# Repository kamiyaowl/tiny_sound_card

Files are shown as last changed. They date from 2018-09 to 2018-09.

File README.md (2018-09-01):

# tiny_sound_card
名刺サイズのボードでArduino Pro Mini同等のボードで、mp3を再生したりできるモジュール

ドア開閉時の音声再生モジュールや簡易mp3プレイヤーを簡単に制作できます。

3d image

## 特徴

* Arduino Pro Miniと同じ開発環境で開発を行え、mp3の音声再生が簡単に行なえます
* スイッチ、mp3再生モジュール、外部スイッチ、SPI、I2Cの準備がしており拡張が容易です
* 表面実装部品が2個のみと、はんだづけの難易度が低いです
* 殆どの部品を秋月電子で購入可能です

## HW仕様

ピン番号 | ボード機能 | ピン機能 | 備考
--------|-------|------|---
D0 | PinHeader | UART RXD | Arduino Bootloader書き込み用
D1 | PinHeader | UART TXD | Arduino Bootloader書き込み用
D2 | LED | Digital Output |
D3 | PinHeader | Digital Input | スイッチ入力用。チャタリング防止回路有
D4 | SW0 | Digital Input | スライドスイッチ
D5 | BTN0 | Digital Input | タクトスイッチ0
D6 | BTN1 | Digital Input | タクトスイッチ1
D7 | BTN2 | Digital Input | タクトスイッチ2
D8 | BTN3 | Digital Input | タクトスイッチ3
D9 | mp3player Control | UART TXD | mp3モジュール制御用
D10 | PinHeader | Digital Output | 外部モジュール接続用SPI
D11 | PinHeader | SPI MOSI | 外部モジュール接続用SPI
D12 | PinHeader | SPI MISO | 外部モジュール接続用SPI
D13 | PinHeader | SPI SCK | 外部モジュール接続用SPI
A0(D14) | mp3player Control | UART RXD | mp3モジュール制御用
A1(D15) | mp3player Control | Digital Input | mp3player再生中にLow
A2(D16) | mp3player Power Control | Digital Output | mp3player電源EN
A3(D17) | mp3player Power Control | Digital Input | mp3player電源/FAULT
A4 | PinHeader | I2C SDA | 外部モジュール接続用I2C
A5 | PinHeader | I2C SCL | 外部モジュール接続用I2C

* スイッチ回路(D3,4,5,6,7,8)にはチャタリング防止回路を実装
* SPI端子はISP(In System Programming)回路も兼用しています
* mp3 playerとはSoftwareSerialを使用して通信を行います
  * [Datasheet](http://akizukidenshi.com/download/ds/dfrobot/DFPlayer_Mini_Manual.pdf)
* mp3 playerモジュールの消費電力が大きいため、ハイサイドスイッチで電源断できるようになっています
  * 不要であれば、U1の1-5pinを短絡してください
   * [Datasheet](https://docs-apac.rs-online.com/webdocs/140d/0900766b8140da8f.pdf)

## SW仕様

準備予定

## 製造ファイル

| ファイルパス | 種別 |
| --- | --- |
`kicad/gerber` | 基盤製造ファイル
`kicad/acrylic_cover/tiny_sound_card-Eco1.User.svg` | 表面アクリルカバー
`kicad/acrylic_cover/tiny_sound_card-Eco2.User.svg` | 裏面アクリルカバー

## 購入部品

| 参照記号 | 購入先 | 数量 | URL |
|---|---|----|---|
| U1 | RS Components | 1  | https://jp.rs-online.com/web/p/intelligent-power-switches/8805406/ |
| R7,R9,R10,R11,R12,R13 | 秋月 | 1  | http://akizukidenshi.com/catalog/g/gR-25473/ |
| R2,R3,R6 | 秋月 | 1  | http://akizukidenshi.com/catalog/g/gR-25103/ |
| R1,R4 | 秋月 | 1  | http://akizukidenshi.com/catalog/g/gR-25102/ |
| CP1 | 秋月 | 1  | http://akizukidenshi.com/catalog/g/gP-10596/ |
| SW1,SW5 | 秋月 | 1  | http://akizukidenshi.com/catalog/g/gP-08789/ |
| Y1 | 秋月 | 1  | http://akizukidenshi.com/catalog/g/gP-08671/ |
| C4,C5 | 秋月 | 1  | http://akizukidenshi.com/catalog/g/gP-04060/ |
| SW2,SW3,SW4,SW6 | 秋月 | 4  | http://akizukidenshi.com/catalog/g/gP-03647/ |
| F1 | 秋月 | 1  | http://akizukidenshi.com/catalog/g/gP-00777/ |
| C1,C2,C3,C6,C7,C9,C10,C11,C12,C13 | 秋月 | 1  | http://akizukidenshi.com/catalog/g/gP-00090/ |
| M1 | 秋月 | 1  | http://akizukidenshi.com/catalog/g/gM-12544/ |
| D1 | 秋月 | 1  | http://akizukidenshi.com/catalog/g/gI-11578/ |
| IC1 | 秋月 | 1  | http://akizukidenshi.com/catalog/g/gI-04386/ |
| J1 | 秋月 | 1  | http://akizukidenshi.com/catalog/g/gC-02460/ |
| P2 | 秋月 | 1  | http://akizukidenshi.com/catalog/g/gC-01627/ |
| CON1 | 秋月 | 1  | http://akizukidenshi.com/catalog/g/gC-00077/ |

## License

MIT

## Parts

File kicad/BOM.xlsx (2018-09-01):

ID | 参照記号 | 購入先 | 数量 | URL
15 | U1 | RS Components | 1 | https://jp.rs-online.com/web/p/intelligent-power-switches/8805406/
13 | R7,R9,R10,R11,R12,R13 | 秋月 | 1 | http://akizukidenshi.com/catalog/g/gR-25473/
12 | R2,R3,R6 | 秋月 | 1 | http://akizukidenshi.com/catalog/g/gR-25103/
23 | R1,R4 | 秋月 | 1 | http://akizukidenshi.com/catalog/g/gR-25102/
21 | CP1 | 秋月 | 1 | http://akizukidenshi.com/catalog/g/gP-10596/
14 | SW1,SW5 | 秋月 | 1 | http://akizukidenshi.com/catalog/g/gP-08789/
16 | Y1 | 秋月 | 1 | http://akizukidenshi.com/catalog/g/gP-08671/
3 | C4,C5 | 秋月 | 1 | http://akizukidenshi.com/catalog/g/gP-04060/
22 | SW2,SW3,SW4,SW6 | 秋月 | 4 | http://akizukidenshi.com/catalog/g/gP-03647/
6 | F1 | 秋月 | 1 | http://akizukidenshi.com/catalog/g/gP-00777/
2 | C1,C2,C3,C6,C7,C9,C10,C11,C12,C13 | 秋月 | 1 | http://akizukidenshi.com/catalog/g/gP-00090/
17 | M1 | 秋月 | 1 | http://akizukidenshi.com/catalog/g/gM-12544/
5 | D1 | 秋月 | 1 | http://akizukidenshi.com/catalog/g/gI-11578/
7 | IC1 | 秋月 | 1 | http://akizukidenshi.com/catalog/g/gI-04386/
8 | J1 | 秋月 | 1 | http://akizukidenshi.com/catalog/g/gC-02460/
10 | P2 | 秋月 | 1 | http://akizukidenshi.com/catalog/g/gC-01627/
4 | CON1 | 秋月 | 1 | http://akizukidenshi.com/catalog/g/gC-00077/
24 | G***
1 | P10,P9,P8,P4
11 | P5
9 | P1
18 | P4
19 | P6
20 | P7

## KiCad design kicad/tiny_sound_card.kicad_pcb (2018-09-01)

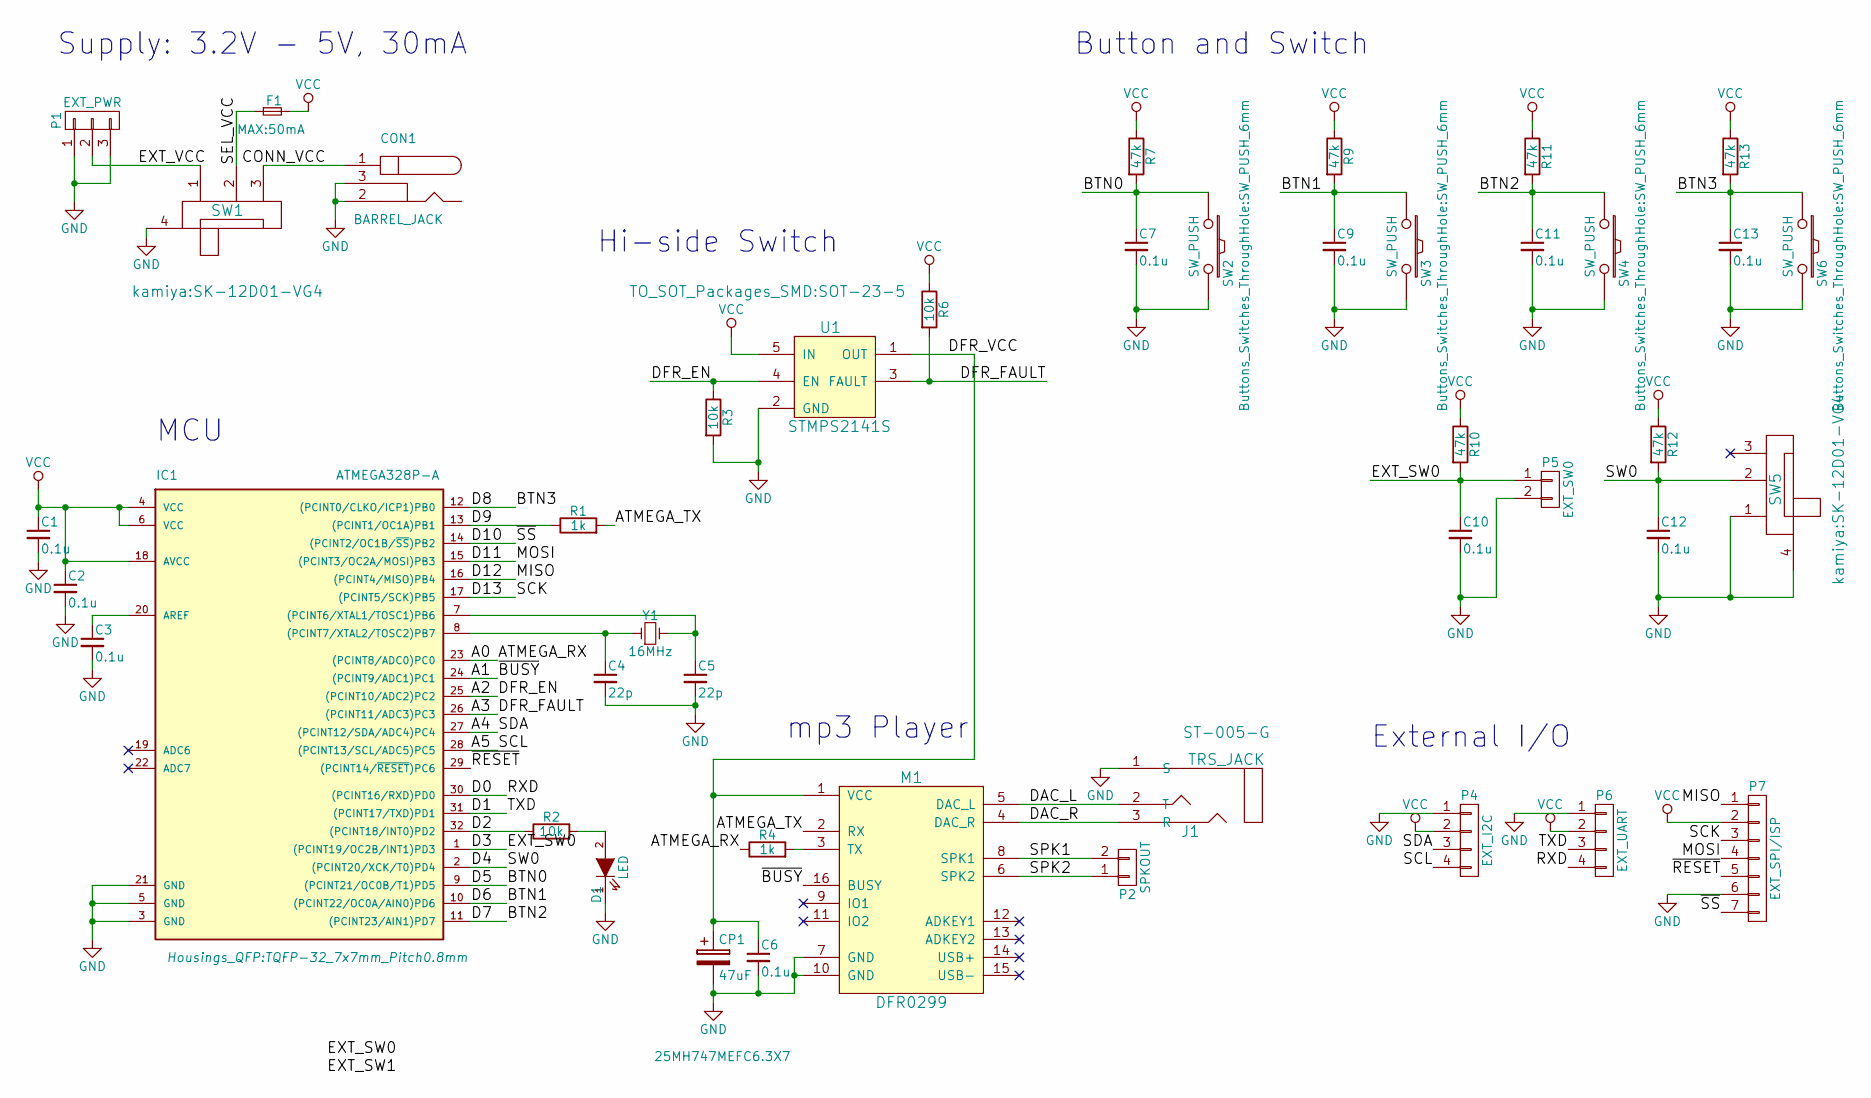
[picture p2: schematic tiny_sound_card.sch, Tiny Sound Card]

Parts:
C1, C2, C3, C6, C7, C9, C10, C11, C12, C13: 0.1u; C_Disc_D3.8mm_W2.6mm_P2.50mm
C4, C5: 22p; C_Disc_D3.8mm_W2.6mm_P2.50mm
CON1: BARREL_JACK
CP1: 47uF; CP_Radial_D10.0mm_P2.50mm
D1: LED; LED_D3.0mm
F1: MAX:50mA; C_Rect_L7.0mm_W4.5mm_P5.00mm
IC1: ATMEGA328P-A; TQFP-32_7x7mm_Pitch0.8mm
J1: TRS_JACK; 3.5mm_TRS_Mini
M1: DFR0299
P1: EXT_PWR; Pin_Header_Angled_1x03_Pitch2.54mm
P2: SPKOUT; Pin_Header_Angled_1x02_Pitch2.54mm
P4: EXT_I2C; Pin_Header_Angled_1x04_Pitch2.54mm
P5: EXT_SW0; Pin_Header_Angled_1x02_Pitch2.54mm
P6: EXT_UART; Pin_Header_Angled_1x04_Pitch2.54mm
P7: EXT_SPI/ISP; Pin_Header_Angled_1x07_Pitch2.54mm
R1, R4: 1k; R_Axial_DIN0207_L6.3mm_D2.5mm_P10.16mm_Horizontal
R2, R3, R6: 10k; R_Axial_DIN0207_L6.3mm_D2.5mm_P10.16mm_Horizontal
R7, R9, R10, R11, R12, R13: 47k; R_Axial_DIN0207_L6.3mm_D2.5mm_P10.16mm_Horizontal
SW1, SW5: SlideSW; SK-12D01-VG4
SW2, SW3, SW4, SW6: SW_PUSH; SW_PUSH_6mm
U1: STMPS2141S; SOT-23-5
Y1: 16MHz; Crystal_HC49-4H_Vertical

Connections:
/A0: IC1.23 ((PCINT8/ADC0)PC0), R4.1
/A1: IC1.24 ((PCINT9/ADC1)PC1), M1.16 (BUSY)
/A2: IC1.25 ((PCINT10/ADC2)PC2), R3.1, U1.4 (EN)
/A3: IC1.26 ((PCINT11/ADC3)PC3), R6.2, U1.3 (FAULT)
/A4: IC1.27 ((PCINT12/SDA/ADC4)PC4), P4.3
/A5: IC1.28 ((PCINT13/SCL/ADC5)PC5), P4.4
/ATMEGA_TX: M1.2 (RX), R1.2
/BTN0: C7.1, IC1.9 ((PCINT21/OC0B/T1)PD5), R7.2, SW2.1
/BTN1: C9.1, IC1.10 ((PCINT22/OC0A/AIN0)PD6), R9.2, SW3.1
/BTN2: C11.1, IC1.11 ((PCINT23/AIN1)PD7), R11.2, SW4.1
/BTN3: C13.1, IC1.12 ((PCINT0/CLKO/ICP1)PB0), R13.2, SW6.1
/CONN_VCC: CON1.1, SW1.3
/D0: IC1.30 ((PCINT16/RXD)PD0), P6.4
/D1: IC1.31 ((PCINT17/TXD)PD1), P6.3
/D2: IC1.32 ((PCINT18/INT0)PD2), R2.1
/D3: C10.1, IC1.1 ((PCINT19/OC2B/INT1)PD3), P5.1, R10.2
/D4: C12.1, IC1.2 ((PCINT20/XCK/T0)PD4), R12.2, SW5.2
/D9: IC1.13 ((PCINT1/OC1A)PB1), R1.1
/D10: IC1.14 ((PCINT2/OC1B/~SS~)PB2), P7.7
/D11: IC1.15 ((PCINT3/OC2A/MOSI)PB3), P7.4
/D12: IC1.16 ((PCINT4/MISO)PB4), P7.1
/D13: IC1.17 ((PCINT5/SCK)PB5), P7.3
/DAC_L: J1.2 (T), M1.5 (DAC_L)
/DAC_R: J1.3 (R), M1.4 (DAC_R)
/DFR_VCC: C6.1, CP1.1, M1.1 (VCC), U1.1 (OUT)
/EXT_VCC: P1.2, SW1.1
/SEL_VCC: F1.1, SW1.2
/SPK1: M1.8 (SPK1), P2.2
/SPK2: M1.6 (SPK2), P2.1
/~RESET: IC1.29 ((PCINT14/~RESET~)PC6), P7.5
GND: C1.2, C2.2, C3.2, C4.2, C5.2, C6.2, C7.2, C9.2, C10.2, C11.2, C12.2, C13.2, CON1.2, CON1.3, CP1.2, D1.1 (K), IC1.3 (GND), IC1.5 (GND), IC1.21 (GND), J1.1 (S), M1.7 (GND), M1.10 (GND), P1.1, P1.3, P4.1, P5.2, P6.1, P7.6, R3.2, SW1.4, SW2.2, SW3.2, SW4.2, SW5.1, SW5.4, SW6.2, U1.2 (GND)
unnamed: C3.1, IC1.20 (AREF)
unnamed: C4.1, IC1.8 ((PCINT7/XTAL2/TOSC2)PB7), Y1.1
unnamed: C5.1, IC1.7 ((PCINT6/XTAL1/TOSC1)PB6), Y1.2
unnamed: D1.2 (A), R2.2
unnamed: M1.3 (TX), R4.2
VCC: C1.1, C2.1, F1.2, IC1.4 (VCC), IC1.6 (VCC), IC1.18 (AVCC), P4.2, P6.2, P7.2, R6.1, R7.1, R9.1, R10.1, R11.1, R12.1, R13.1, U1.5 (IN)

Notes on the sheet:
Supply: 3.2V - 5V, 30mA
Button and Switch
MCU
Hi-side Switch
mp3 Player
External I/O

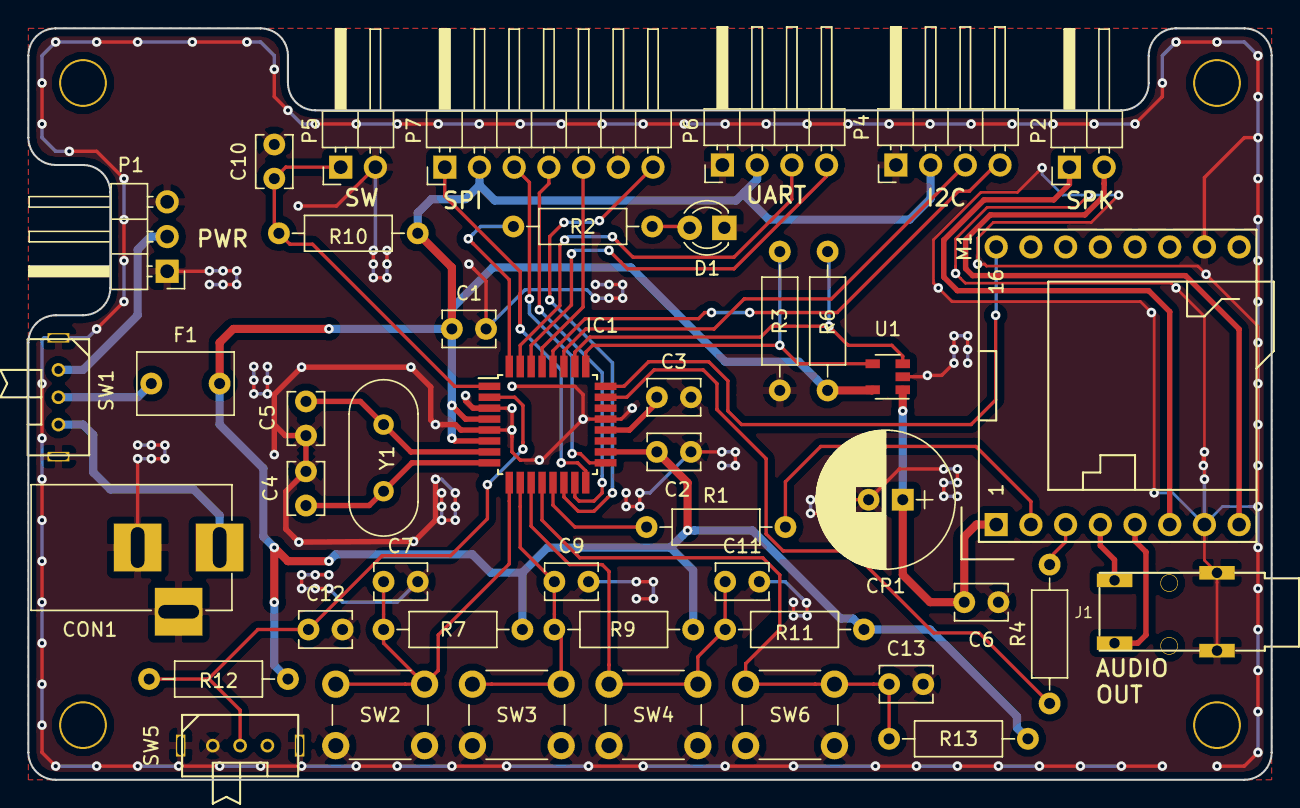
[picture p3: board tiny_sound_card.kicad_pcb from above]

Board: 2 copper layers, 91.0 x 55.0 mm, 48 parts (0 on the bottom side), 37 nets.

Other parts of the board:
P4#2, P8, P9, P10: M3Drill; M3Drill2

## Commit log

2018-08-19 回路図を作成
    [tiny_sound_card.kicad_pcb, tiny_sound_card.sch]
2018-08-19 部品割当の修正と、配置を完了
    [tiny_sound_card.kicad_pcb, tiny_sound_card.sch]
2018-08-19 デザインルールを設定
    [tiny_sound_card.kicad_pcb]
2018-08-19 GPIOのアサインを大幅に調整
    [tiny_sound_card.kicad_pcb, tiny_sound_card.sch]
2018-08-19 基本配線終わり
    [tiny_sound_card.kicad_pcb]
2018-08-19 外形とパネル表裏を作成
    [tiny_sound_card.kicad_pcb]
2018-08-20 LEDのポートを変更
    [tiny_sound_card.kicad_pcb, tiny_sound_card.sch]
2018-08-20 EXT_SW1を削除
    [tiny_sound_card.kicad_pcb, tiny_sound_card.sch]
2018-08-20 ベタ配線
    [tiny_sound_card.kicad_pcb]
2018-08-20 シルク位置修正
    [tiny_sound_card.kicad_pcb]
2018-09-01 Close #1
    [tiny_sound_card.kicad_pcb, tiny_sound_card.sch]
2018-09-01 ロゴ追加
    [tiny_sound_card.kicad_pcb]
2018-09-01 シルクでピンアサイン記述を追加
    [tiny_sound_card.kicad_pcb]
2018-09-01 Update README.md
    HW使用に関して追記
2018-09-01 gerber,acrylicの製造ファイルを作成
    [tiny_sound_card-B.Cu.gbl, tiny_sound_card-B.Mask.gbs, tiny_sound_card-B.SilkS.gbo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]
2018-09-01 BOM作成、READMEに反映
    [BOM.xlsx, tiny_sound_card.kicad_pcb]
